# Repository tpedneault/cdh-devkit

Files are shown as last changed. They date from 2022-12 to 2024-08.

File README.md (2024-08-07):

# Define the color scheme
set colors(bg) "#ECEFF4"
set colors(bg_secondary) "#E5E9F0"
set colors(bg_highlight) "#D8DEE9"
set colors(fg) "#2E3440"
set colors(fg_secondary) "#3B4252"
set colors(fg_highlight) "#4C566A"
set colors(accent) "#5E81AC"
set colors(accent_hover) "#81A1C1"
set colors(accent_active) "#88C0D0"
set colors(border) "#D8DEE9"
set colors(border_focus) "#5E81AC"
set colors(border_disabled) "#E5E9F0"
set colors(button_bg) "#88C0D0"
set colors(button_fg) "#2E3440"
set colors(button_hover_bg) "#81A1C1"
set colors(button_active_bg) "#5E81AC"
set colors(input_bg) "#E5E9F0"
set colors(input_fg) "#2E3440"
set colors(input_border) "#D8DEE9"
set colors(alert_success_bg) "#A3BE8C"
set colors(alert_success_fg) "#2E3440"
set colors(alert_warning_bg) "#EBCB8B"
set colors(alert_warning_fg) "#2E3440"
set colors(alert_error_bg) "#BF616A"
set colors(alert_error_fg) "#2E3440"

# Create the main window
ttk::style configure TFrame -background $colors(bg)
ttk::style configure TLabel -background $colors(bg) -foreground $colors(fg)
ttk::style configure TButton -background $colors(button_bg) -foreground $colors(button_fg) -padding 6 -relief flat
ttk::style map TButton -background {active $colors(button_active_bg) pressed $colors(button_active_bg) focus $colors(accent_active)}
ttk::style configure TEntry -fieldbackground $colors(input_bg) -foreground $colors(input_fg) -relief solid -padding 6
ttk::style configure TCheckbutton -background $colors(bg) -foreground $colors(fg)
ttk::style configure TRadiobutton -background $colors(bg) -foreground $colors(fg)
ttk::style configure TCombobox -fieldbackground $colors(input_bg) -foreground $colors(input_fg) -relief solid -padding 6
ttk::style configure TSpinbox -fieldbackground $colors(input_bg) -foreground $colors(input_fg) -relief solid -padding 6
ttk::style configure TLabelframe -background $colors(bg) -foreground $colors(fg) -padding 10
ttk::style configure TLabelframe.Label -background $colors(bg) -foreground $colors(fg)
ttk::style configure Treeview -background $colors(bg_secondary) -foreground $colors(fg) -fieldbackground $colors(bg_secondary)
ttk::style configure Treeview.Heading -background $colors(bg_highlight) -foreground $colors(fg_highlight)
ttk::style configure TNotebook -background $colors(bg)
ttk::style configure TNotebook.Tab -background $colors(bg) -foreground $colors(fg)
ttk::style configure Horizontal.TScrollbar -background $colors(border)
ttk::style configure Vertical.TScrollbar -background $colors(border)
ttk::style configure TProgressbar -background $colors(accent)
ttk::style configure TSeparator -background $colors(border)
ttk::style configure TSizegrip -background $colors(bg_secondary)

# Create a sample GUI
ttk::frame .frame -padding "10 10 10 10"
grid .frame -column 0 -row 0 -sticky "nwes"

ttk::label .frame.label -text "Hello, World!"
grid .frame.label -column 0 -row 0 -pady 5

ttk::button .frame.button -text "Click Me"
grid .frame.button -column 0 -row 1 -pady 5

ttk::entry .frame.entry
grid .frame.entry -column 0 -row 2 -pady 5

ttk::checkbutton .frame.check -text "Check Me"
grid .frame.check -column 0 -row 3 -pady 5

ttk::radiobutton .frame.radio -text "Option 1" -value 1 -variable option
grid .frame.radio -column 0 -row 4 -pady 5

ttk::combobox .frame.combo -values {Option1 Option2 Option3}
grid .frame.combo -column 0 -row 5 -pady 5

ttk::spinbox .frame.spin -from 0 -to 10
grid .frame.spin -column 0 -row 6 -pady 5

ttk::labelframe .frame.labelframe -text "Group"
grid .frame.labelframe -column 0 -row 7 -pady 5

ttk::notebook .frame.notebook
grid .frame.notebook -column 0 -row 8 -pady 5

ttk::treeview .frame.tree -columns {Name Age}
grid .frame.tree -column 0 -row 9 -pady 5

ttk::progressbar .frame.progress
grid .frame.progress -column 0 -row 10 -pady 5

# Add contents to the labelframe
ttk::label .frame.labelframe.label -text "Inside Group"
grid .frame.labelframe.label -column 0 -row 0 -pady 5

# Add tabs to the notebook
ttk::frame .frame.notebook.tab1
ttk::frame .frame.notebook.tab2
.frame.notebook add .frame.notebook.tab1 -text "Tab 1"
.frame.notebook add .frame.notebook.tab2 -text "Tab 2"

# Add items to the treeview
.frame.tree heading Name -text "Name"
.frame.tree heading Age -text "Age"
.frame.tree insert {} end -values {"Alice" 30}
.frame.tree insert {} end -values {"Bob" 25}

# Start the main loop
tk::mainloop

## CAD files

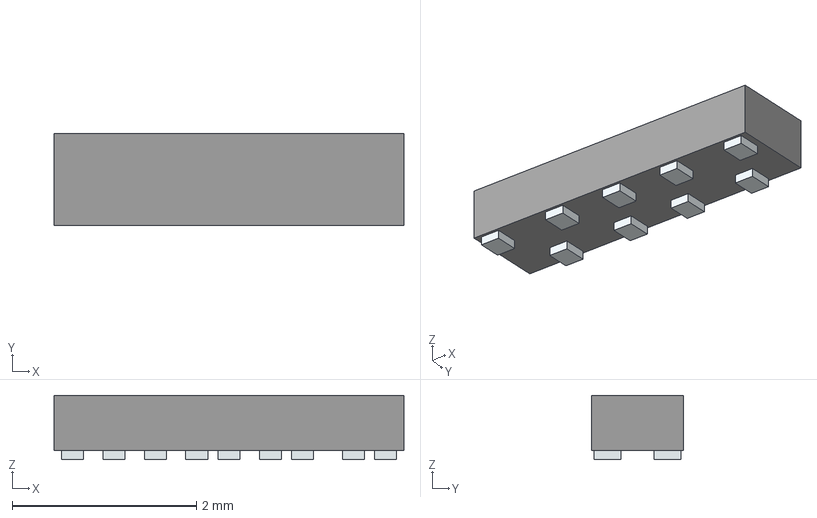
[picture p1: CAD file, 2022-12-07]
Models/DT1240A-08LP3810-7.stp
3.80 x 1.00 x 0.7 mm
Pins

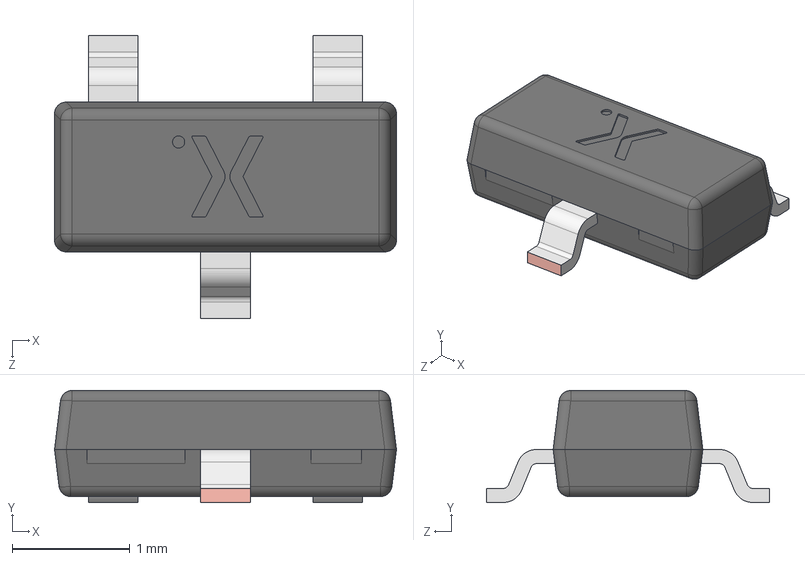
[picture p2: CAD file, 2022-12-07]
Models/PESD2USB3UV-TR.stp
2.90 x 0.95 x 2.40 mm
SOT23 lower body
SOT23 Lead x 3
SOT23 Upper body

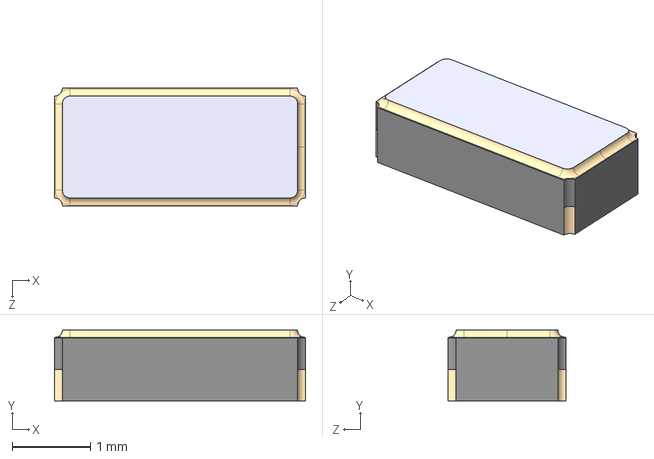
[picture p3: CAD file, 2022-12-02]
Models/NX3215SA-32.768K-STD-MUA-14--3DModel-STEP-1.STEP
3.20 x 0.9 x 1.50 mm

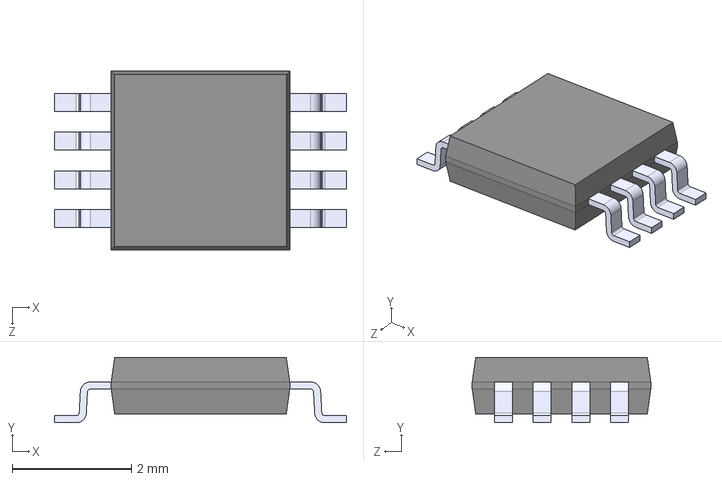
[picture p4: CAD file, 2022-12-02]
Models/DS1339U-33+T&amp;R.STEP
4.91 x 1.10 x 3.00 mm

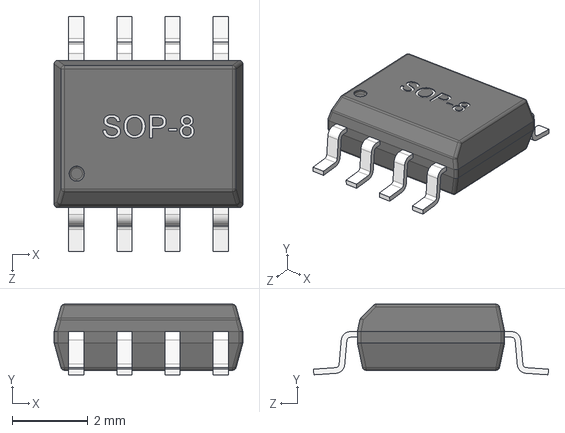
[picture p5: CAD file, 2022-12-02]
Models/SOP-8.STEP
5.00 x 1.87 x 6.22 mm

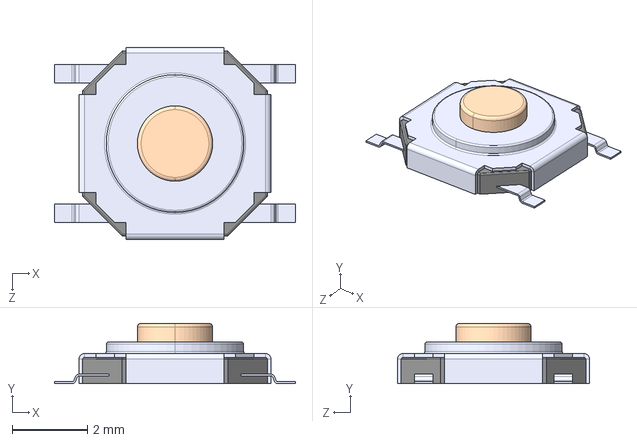
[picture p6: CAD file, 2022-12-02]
Models/PTS525SM15SMTR2LFS--3DModel-STEP-56544.STEP
6.40 x 1.60 x 5.10 mm

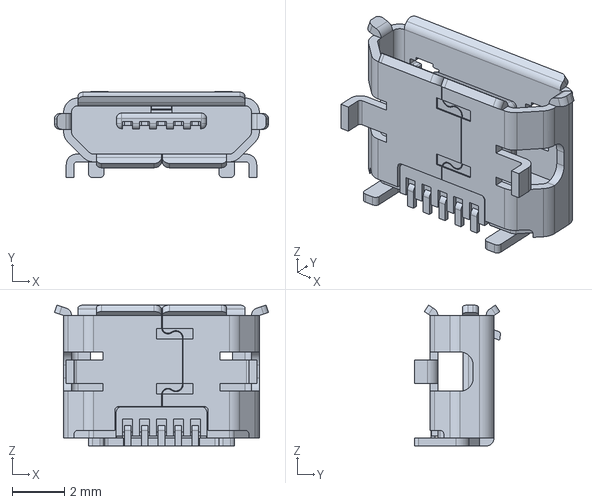
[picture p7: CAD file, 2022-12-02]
Models/105017-0001.stp
8.20 x 3.30 x 5.40 mm

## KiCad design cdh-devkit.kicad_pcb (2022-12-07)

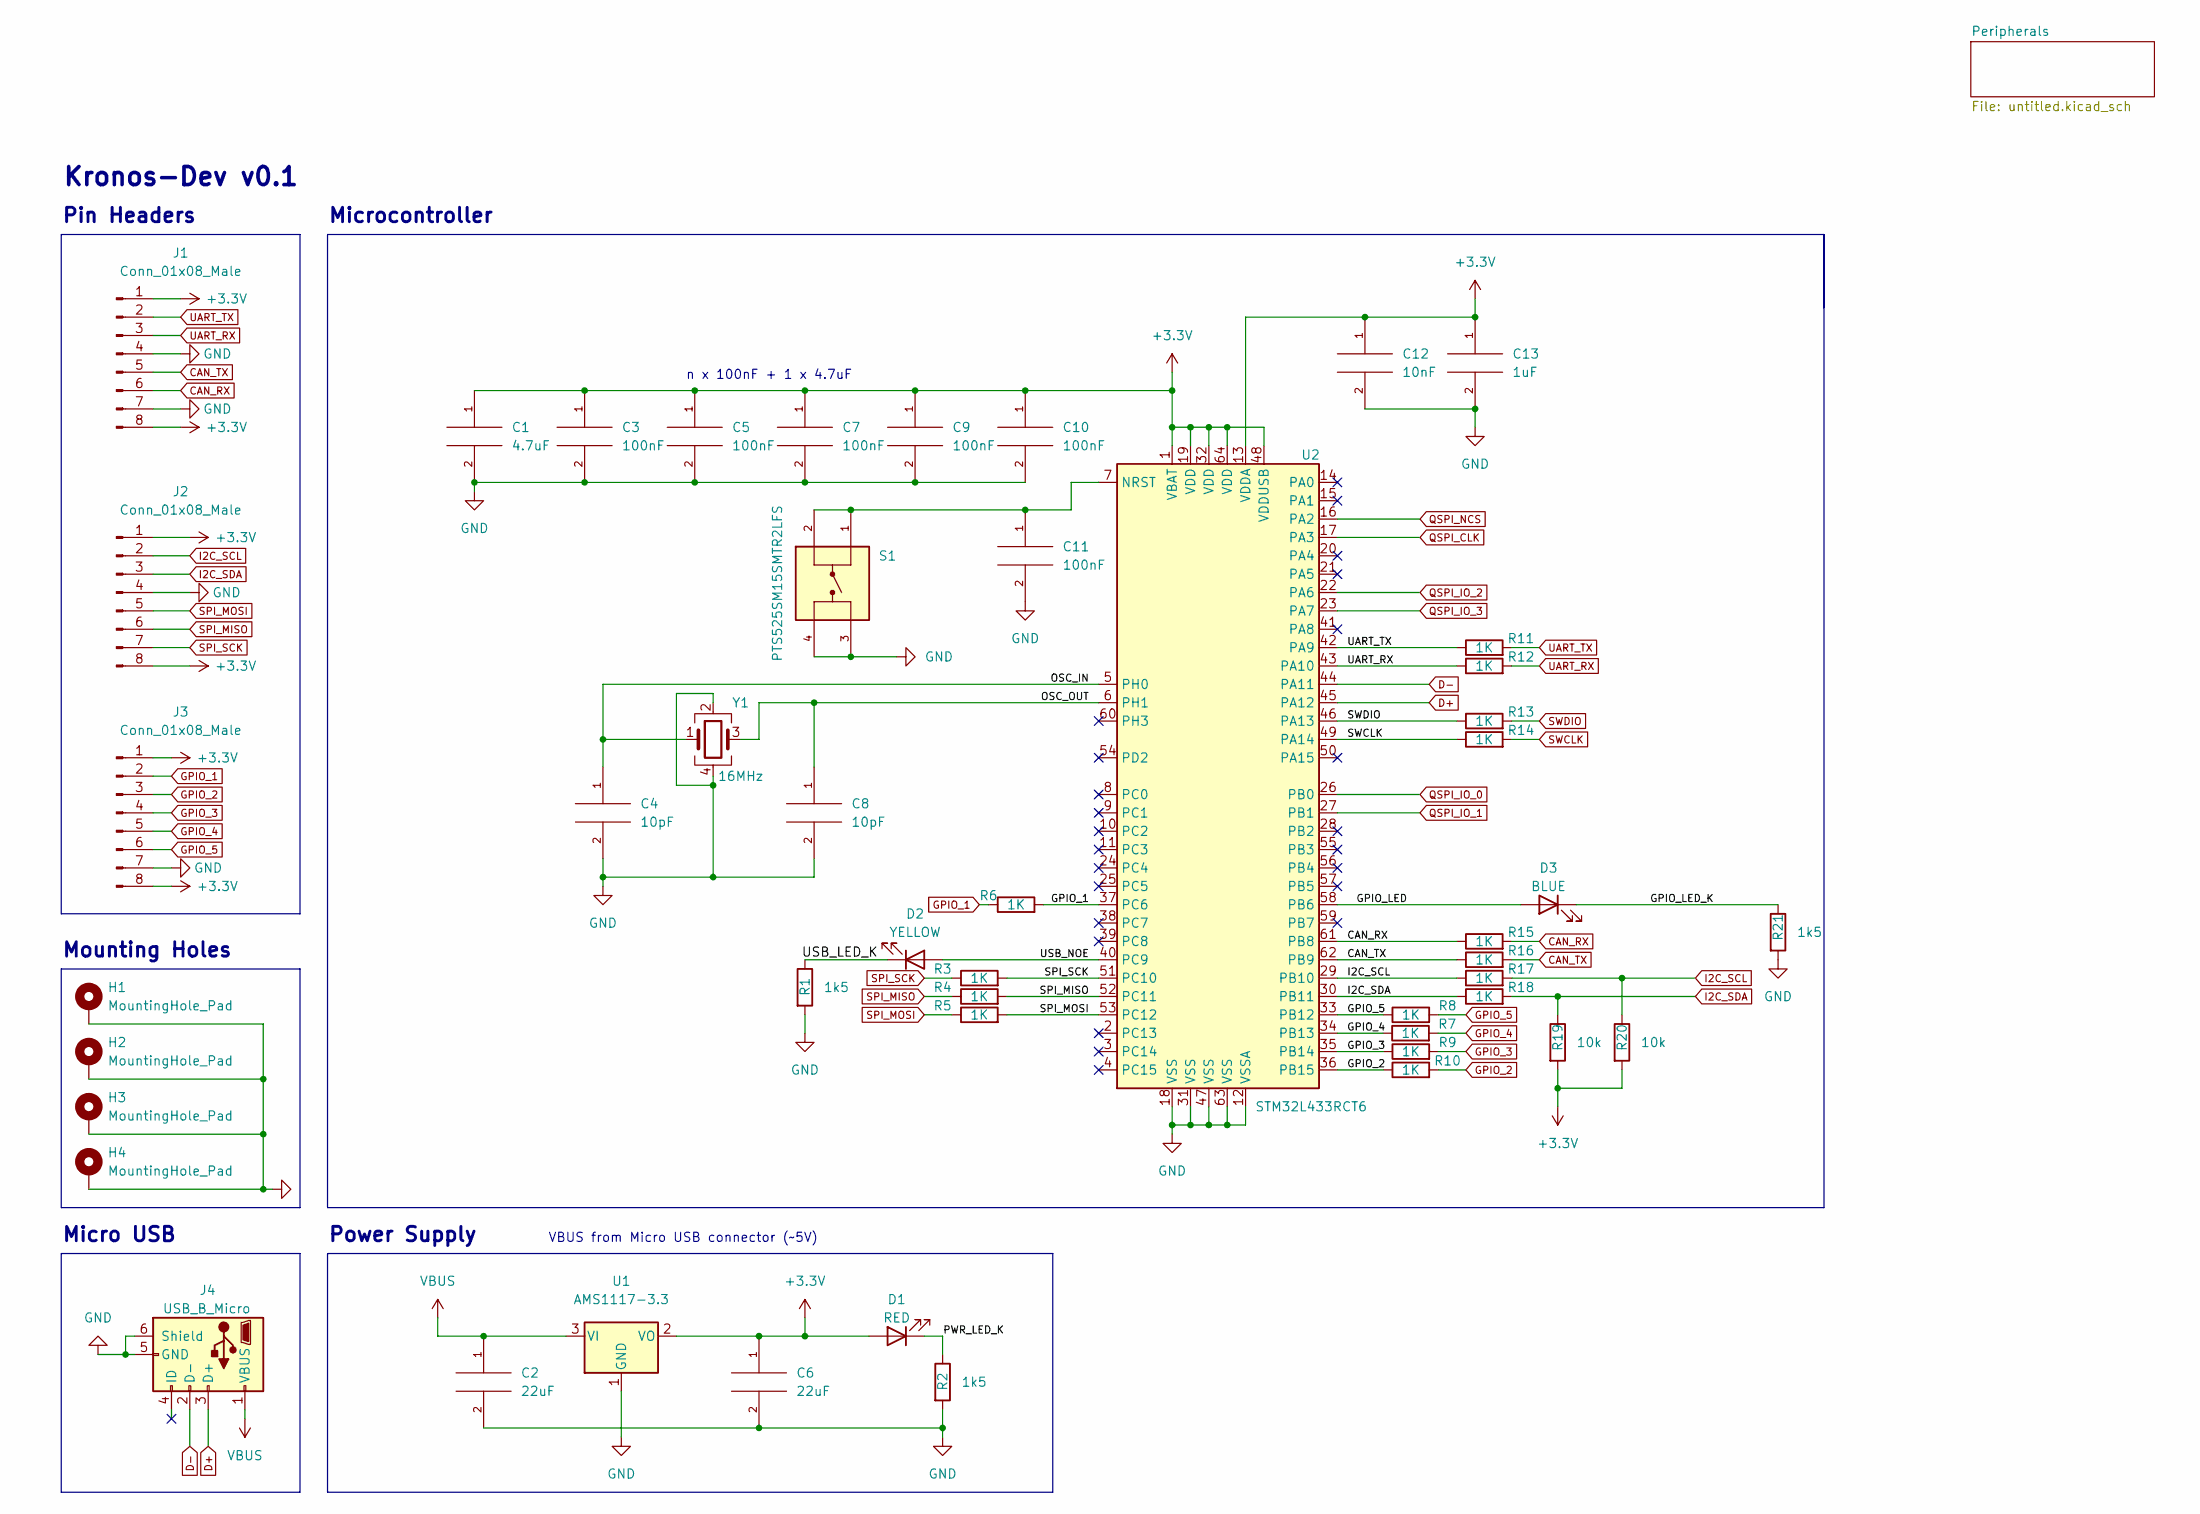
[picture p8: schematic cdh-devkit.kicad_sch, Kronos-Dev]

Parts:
C1: 4.7uF; C_0603_1608Metric
C2, C6: 22uF; C_0805_2012Metric
C3, C5, C7, C9, C10, C11: 100nF; C_0402_1005Metric
C4, C8: 10pF; C_0402_1005Metric
C12: 10nF; C_0402_1005Metric
C13: 1uF; C_0402_1005Metric
D1: RED; LED_0603_1608Metric
D2: YELLOW; LED_0603_1608Metric
D3: BLUE; LED_0603_1608Metric
H1, H2, H3, H4: MountingHole_Pad; MountingHole_2.2mm_M2_Pad
J1, J2, J3: Conn_01x08_Male; PinHeader_1x08_P2.54mm_Vertical
J4: USB_B_Micro; USB_Micro-B_Molex-105017-0001
R1, R2, R21: 1k5; R_0402_1005Metric
R3, R4, R5, R6, R7, R8, R9, R10, R11, R12, R13, R14, R15, R16, R17, R18: 1K; R_0402_1005Metric
R19, R20: 10k; R_0402_1005Metric
S1: PTS525SM15SMTR2LFS; SW_PTS525SM15SMTR2LFS; PARTREV NA
U1: AMS1117-3.3; SOT-223-3_TabPin2
U2: STM32L433RCT6; LQFP-64_10x10mm_P0.5mm
Y1: 16MHz; Crystal_SMD_3225-4Pin_3.2x2.5mm

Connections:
+3.3V: C1.1, C3.1, C5.1, C6.1, C7.1, C9.1, C10.1, C12.1, C13.1, D1.2 (A), J1.1, J1.8, J2.1, J2.8, J3.1, J3.8, R19.2, R20.2, U1.2 (VO), U2.1 (VBAT), U2.13 (VDDA), U2.19 (VDD), U2.32 (VDD), U2.48 (VDDUSB), U2.64 (VDD); also elsewhere on the board
/GPIO_LED: D3.2 (A), U2.58 (PB6)
/GPIO_LED_K: D3.1 (K), R21.1
/OSC_IN: C4.1, U2.5 (PH0), Y1.1
/OSC_OUT: C8.1, U2.6 (PH1), Y1.3
/PWR_LED_K: D1.1 (K), R2.1
/USB_LED_K: D2.1 (K), R1.1
/USB_NOE: D2.2 (A), U2.40 (PC9)
CAN_RX: J1.6, R15.1, R15.2, U2.61 (PB8); also elsewhere on the board
CAN_TX: J1.5, R16.1, R16.2, U2.62 (PB9); also elsewhere on the board
D+: J4.3 (D+), U2.45 (PA12); also elsewhere on the board
D-: J4.2 (D-), U2.44 (PA11); also elsewhere on the board
GND: C1.2, C2.2, C3.2, C4.2, C5.2, C6.2, C7.2, C8.2, C9.2, C10.2, C11.2, C12.2, C13.2, H1.1, H2.1, H3.1, H4.1, J1.4, J1.7, J2.4, J3.7, J4.5 (GND), J4.6 (Shield), R1.2, R2.2, R21.2, S1.3, S1.4, U1.1 (GND), U2.12 (VSSA), U2.18 (VSS), U2.31 (VSS), U2.47 (VSS), U2.63 (VSS), Y1.2, Y1.4; also elsewhere on the board
GPIO_1: J3.2, R6.1, R6.2, U2.37 (PC6); also elsewhere on the board
GPIO_2: J3.3, R10.1, R10.2, U2.36 (PB15); also elsewhere on the board
GPIO_3: J3.4, R9.1, R9.2, U2.35 (PB14); also elsewhere on the board
GPIO_4: J3.5, R7.1, R7.2, U2.34 (PB13); also elsewhere on the board
GPIO_5: J3.6, R8.1, R8.2, U2.33 (PB12); also elsewhere on the board
I2C_SCL: J2.2, R17.1, R17.2, R20.1, U2.29 (PB10); also elsewhere on the board
I2C_SDA: J2.3, R18.1, R18.2, R19.1, U2.30 (PB11); also elsewhere on the board
unnamed: C11.1, S1.1, S1.2, U2.7 (NRST)
QSPI_CLK: U2.17 (PA3); also elsewhere on the board
QSPI_IO_0: U2.26 (PB0); also elsewhere on the board
QSPI_IO_1: U2.27 (PB1); also elsewhere on the board
QSPI_IO_2: U2.22 (PA6); also elsewhere on the board
QSPI_IO_3: U2.23 (PA7); also elsewhere on the board
QSPI_NCS: U2.16 (PA2); also elsewhere on the board
SPI_MISO: J2.6, R4.1, R4.2, U2.52 (PC11); also elsewhere on the board
SPI_MOSI: J2.5, R5.1, R5.2, U2.53 (PC12); also elsewhere on the board
SPI_SCK: J2.7, R3.1, R3.2, U2.51 (PC10); also elsewhere on the board
SWCLK: R14.1, R14.2, U2.49 (PA14); also elsewhere on the board
SWDIO: R13.1, R13.2, U2.46 (PA13); also elsewhere on the board
UART_RX: J1.3, R12.1, R12.2, U2.43 (PA10); also elsewhere on the board
UART_TX: J1.2, R11.1, R11.2, U2.42 (PA9); also elsewhere on the board
VBUS: C2.1, J4.1 (VBUS), U1.3 (VI)

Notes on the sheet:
Power Supply
Pin Headers
VBUS from Micro USB connector (~5V)
Micro USB
Kronos-Dev v0.1
Microcontroller
Mounting Holes
n x 100nF + 1 x 4.7uF

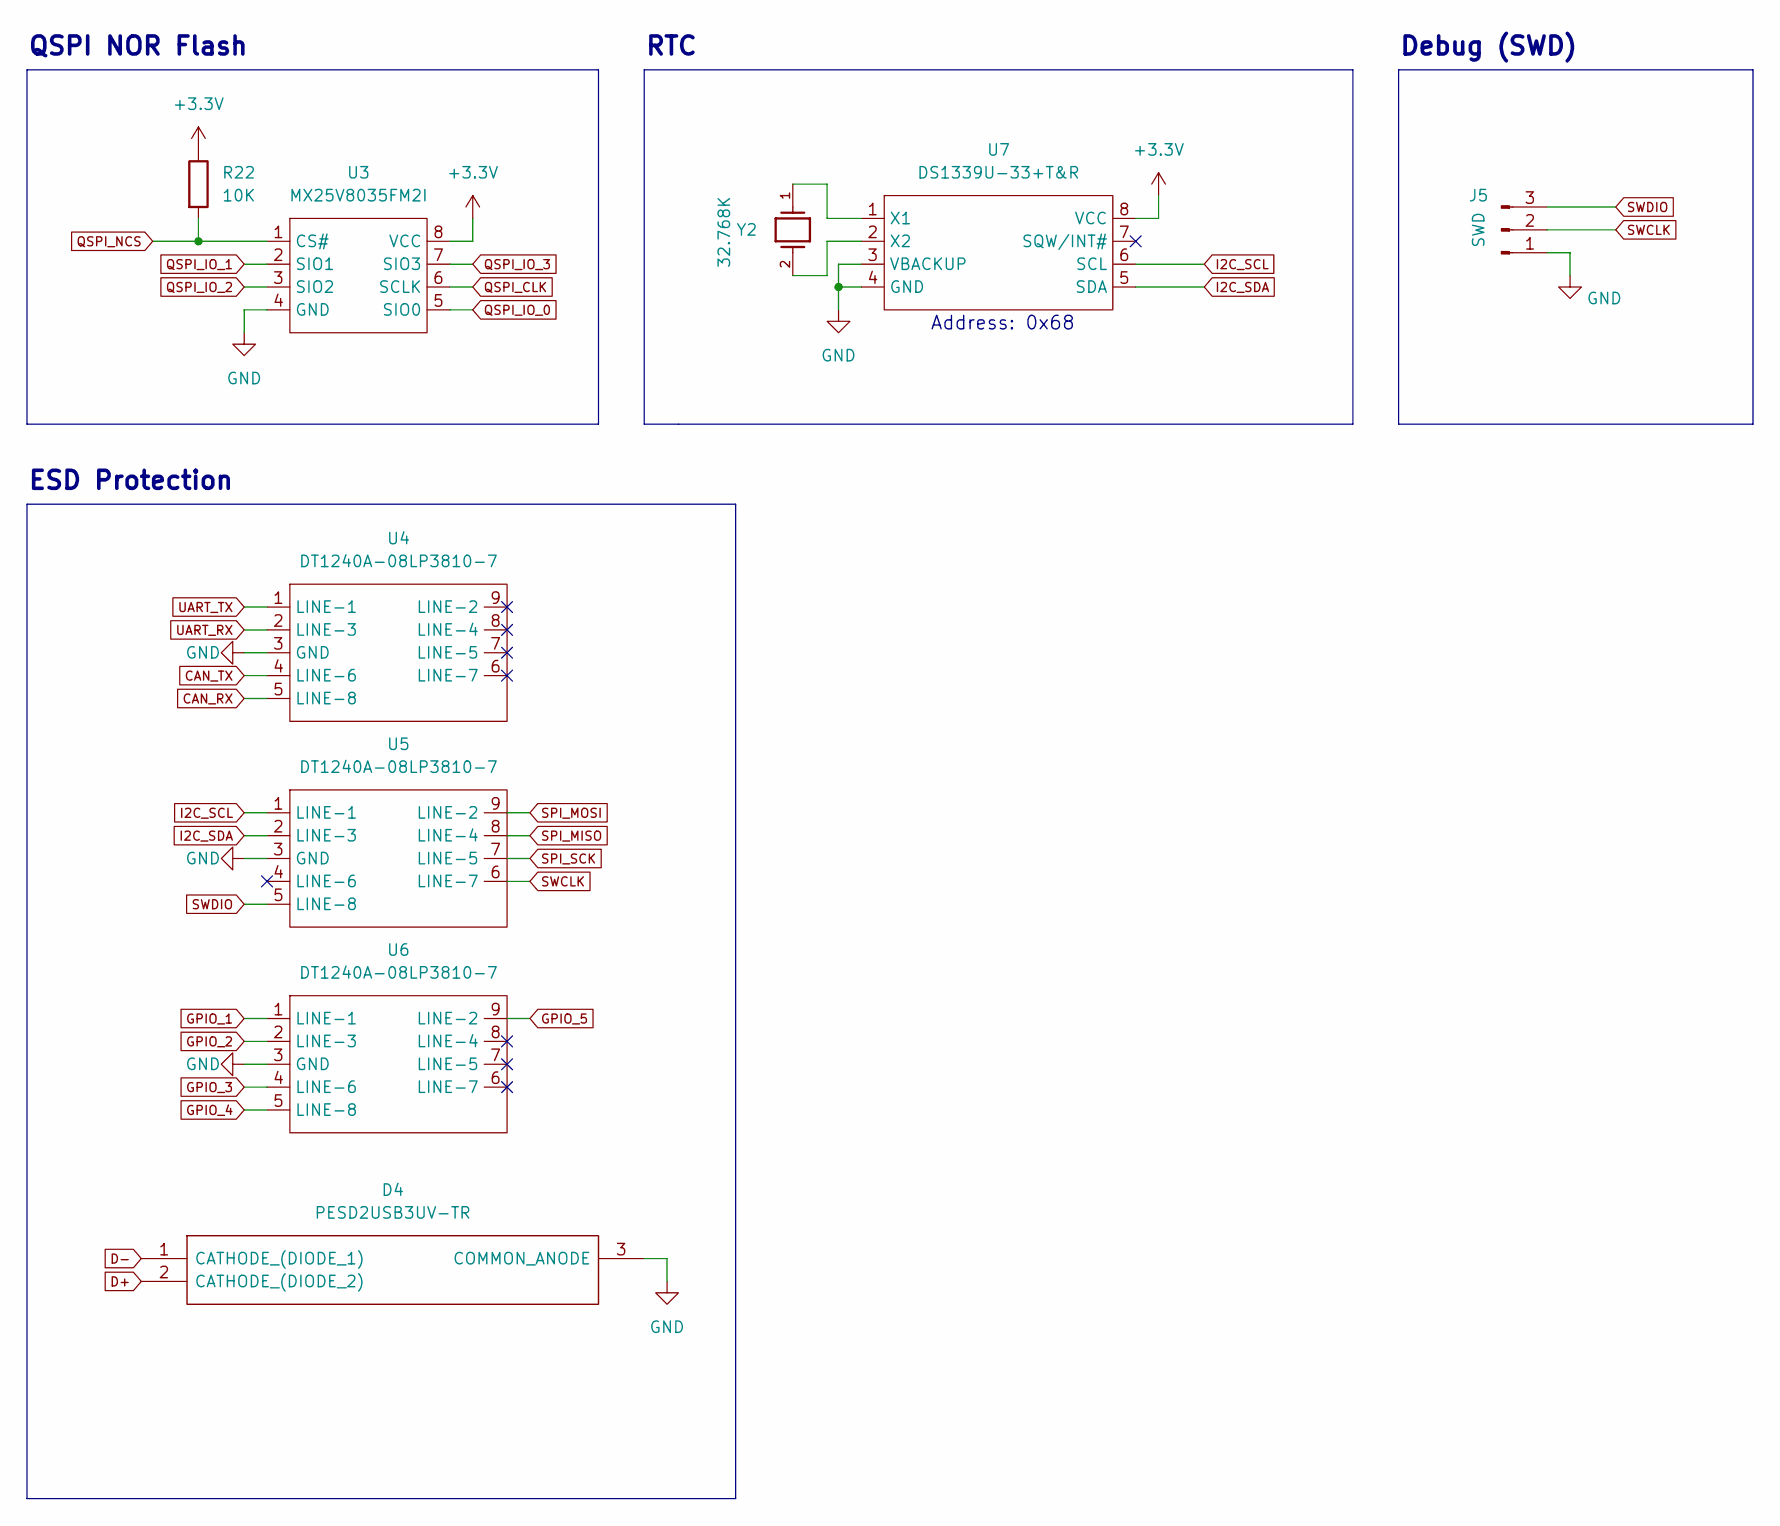
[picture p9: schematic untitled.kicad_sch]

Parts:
D4: PESD2USB3UV-TR; SOT95P230X110-3N; Mouser Part Number 771-PESD2USB3UV-TR
J5: SWD; PinHeader_1x03_P2.54mm_Vertical
R22: 10K; R_0603_1608Metric
U3: MX25V8035FM2I; SOIC127P790X216-8N
U4, U5, U6: DT1240A-08LP3810-7; TVS_824014883
U7: DS1339U-33+T&R; 21-0036K
Y2: 32.768K; XTAL_NX3215SA-32.768K-STD-MUA-14; PARTREV --

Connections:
+3.3V: R22.1, U3.8 (VCC), U7.8 (VCC); also elsewhere on the board
CAN_RX: U4.5 (LINE-8); also elsewhere on the board
CAN_TX: U4.4 (LINE-6); also elsewhere on the board
D+: D4.2 (CATHODE_(DIODE_2)); also elsewhere on the board
D-: D4.1 (CATHODE_(DIODE_1)); also elsewhere on the board
GND: D4.3 (COMMON_ANODE), J5.1, U3.4 (GND), U4.3 (GND), U5.3 (GND), U6.3 (GND), U7.3 (VBACKUP), U7.4 (GND); also elsewhere on the board
GPIO_1: U6.1 (LINE-1); also elsewhere on the board
GPIO_2: U6.2 (LINE-3); also elsewhere on the board
GPIO_3: U6.4 (LINE-6); also elsewhere on the board
GPIO_4: U6.5 (LINE-8); also elsewhere on the board
GPIO_5: U6.9 (LINE-2); also elsewhere on the board
I2C_SCL: U5.1 (LINE-1), U7.6 (SCL); also elsewhere on the board
I2C_SDA: U5.2 (LINE-3), U7.5 (SDA); also elsewhere on the board
unnamed: U7.1 (X1), Y2.1
unnamed: U7.2 (X2), Y2.2
QSPI_CLK: U3.6 (SCLK); also elsewhere on the board
QSPI_IO_0: U3.5 (SIO0); also elsewhere on the board
QSPI_IO_1: U3.2 (SIO1); also elsewhere on the board
QSPI_IO_2: U3.3 (SIO2); also elsewhere on the board
QSPI_IO_3: U3.7 (SIO3); also elsewhere on the board
QSPI_NCS: R22.2, U3.1 (CS#); also elsewhere on the board
SPI_MISO: U5.8 (LINE-4); also elsewhere on the board
SPI_MOSI: U5.9 (LINE-2); also elsewhere on the board
SPI_SCK: U5.7 (LINE-5); also elsewhere on the board
SWCLK: J5.2, U5.6 (LINE-7); also elsewhere on the board
SWDIO: J5.3, U5.5 (LINE-8); also elsewhere on the board
UART_RX: U4.2 (LINE-3); also elsewhere on the board
UART_TX: U4.1 (LINE-1); also elsewhere on the board

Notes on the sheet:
Address: 0x68
RTC
Debug (SWD)
ESD Protection
QSPI NOR Flash

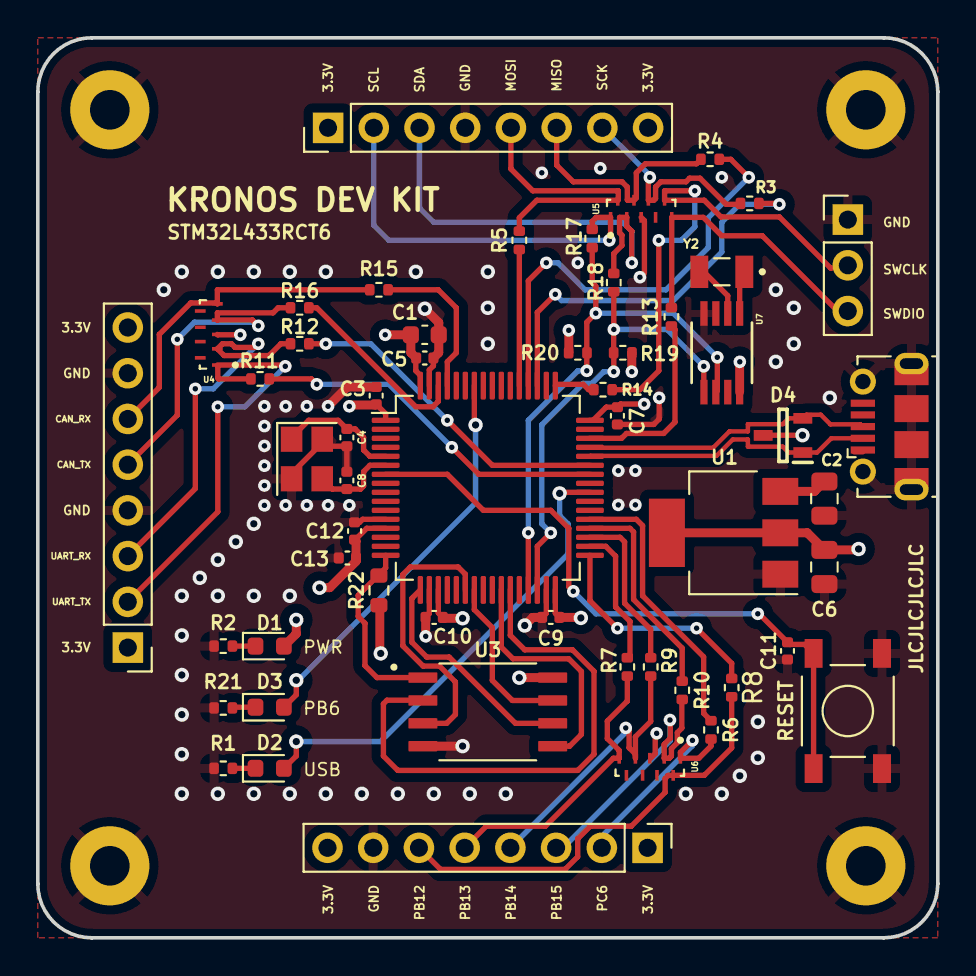
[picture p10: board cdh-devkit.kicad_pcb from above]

Board: 4 copper layers, 50.0 x 50.0 mm, 58 parts (0 on the bottom side), 37 nets.

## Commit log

2022-11-28 added project files
    [cdh-devkit.kicad_pcb, cdh-devkit.kicad_sch, untitled.kicad_sch]
2022-12-02 version 0.1
    [105017-0001.stp, PTS525SM15SMTR2LFS--3DModel-STEP-56544.STEP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]
2022-12-02 v1 - added missing 3D models
    [DS1339U-33+T&amp;R.STEP, NX3215SA-32.768K-STD-MUA-14--3DModel-STEP-1.STEP, SOP-8.STEP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]
2022-12-03 started rerouting
    [cdh-devkit.kicad_pcb, cdh-devkit.kicad_sch]
2022-12-03 updated routes
    [cdh-devkit.kicad_pcb]
2022-12-07 finished second revision
    [DT1240A-08LP3810-7.stp, PESD2USB3UV-TR.stp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]
